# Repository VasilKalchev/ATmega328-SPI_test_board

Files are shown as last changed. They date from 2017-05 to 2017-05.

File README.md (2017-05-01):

# ATmega328-SPI_test_board
ATmega328 test board connected to an SPI device and a few inputs and outputs.

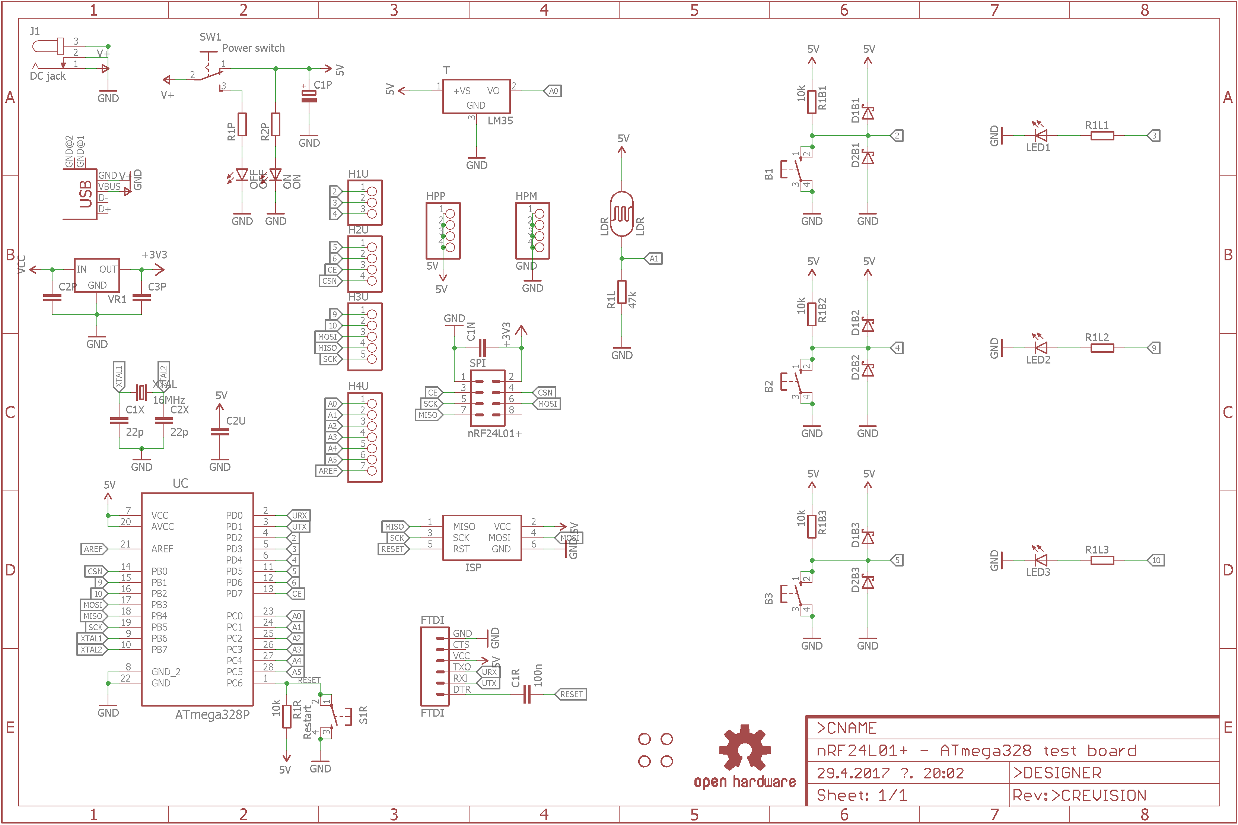
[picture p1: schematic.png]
schematic

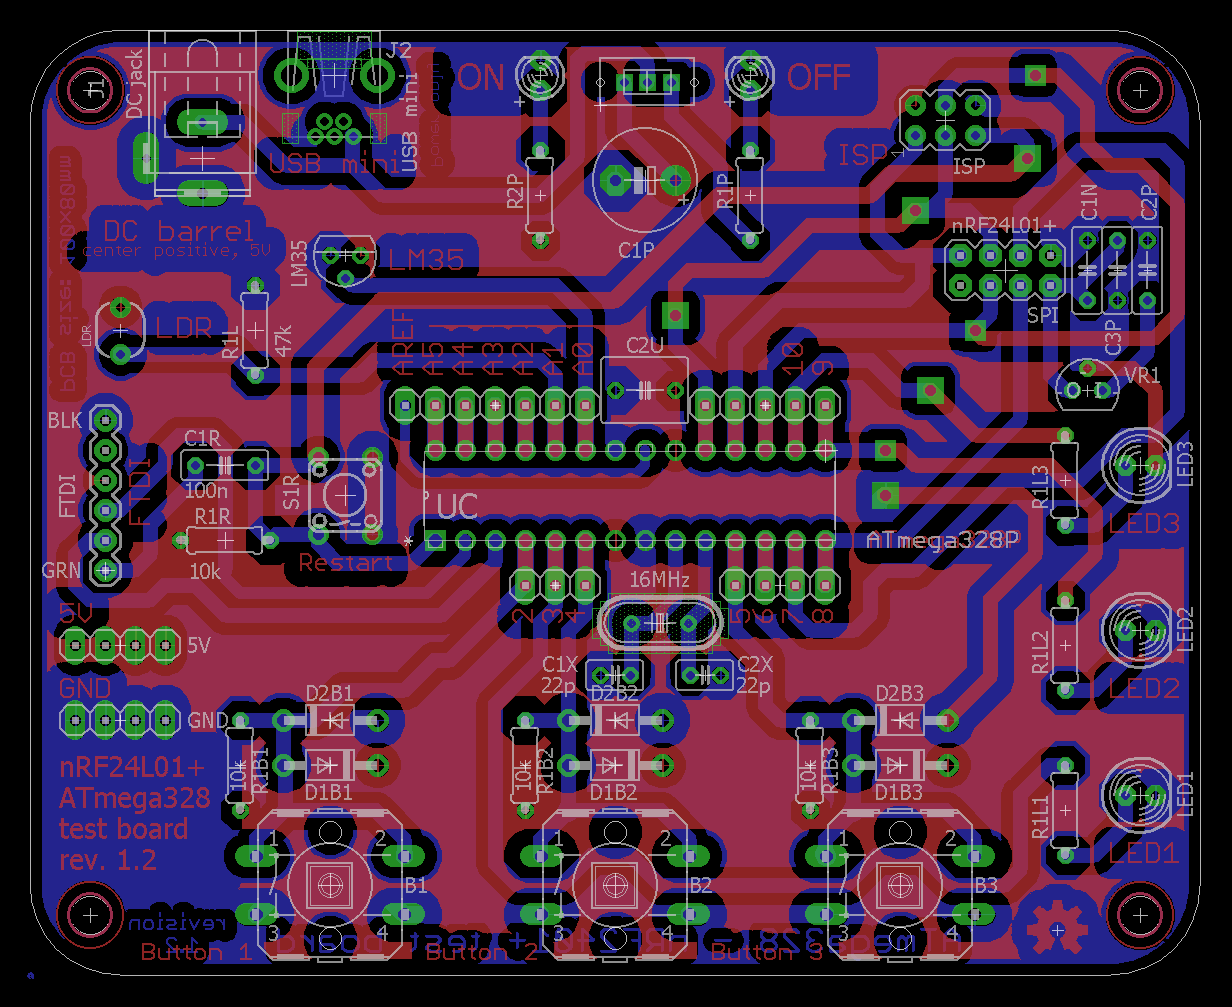
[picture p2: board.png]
board


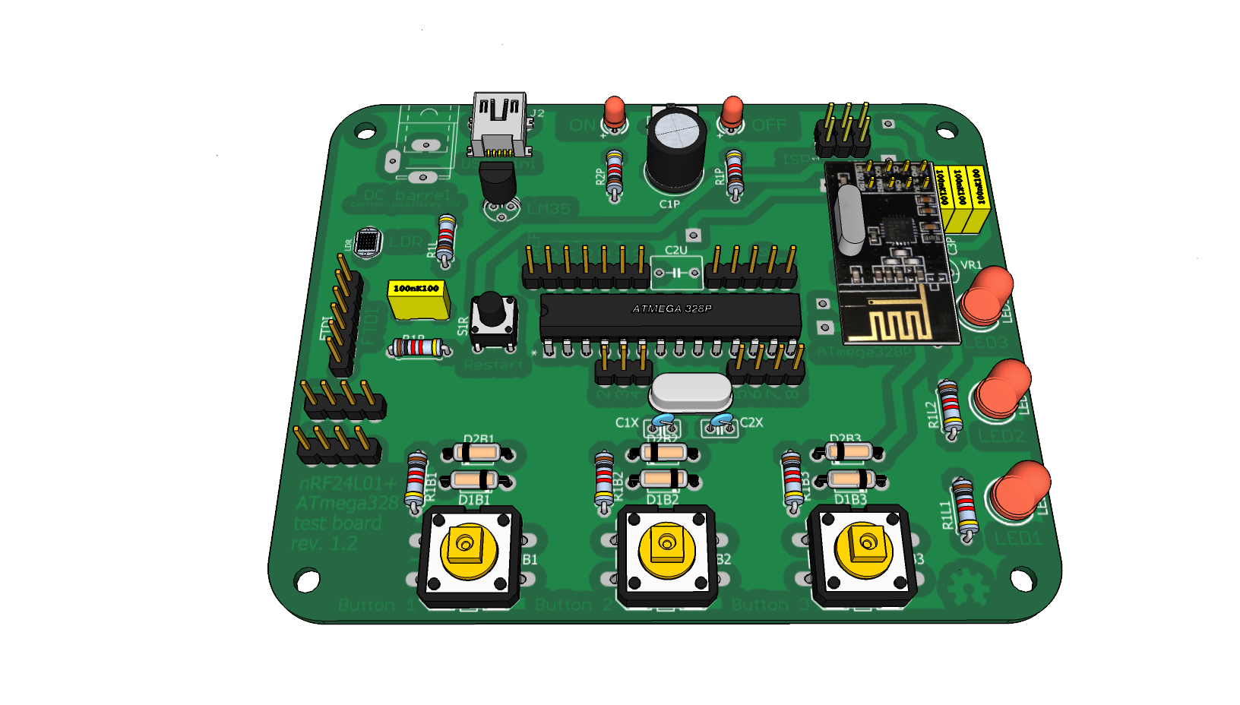
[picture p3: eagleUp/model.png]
model


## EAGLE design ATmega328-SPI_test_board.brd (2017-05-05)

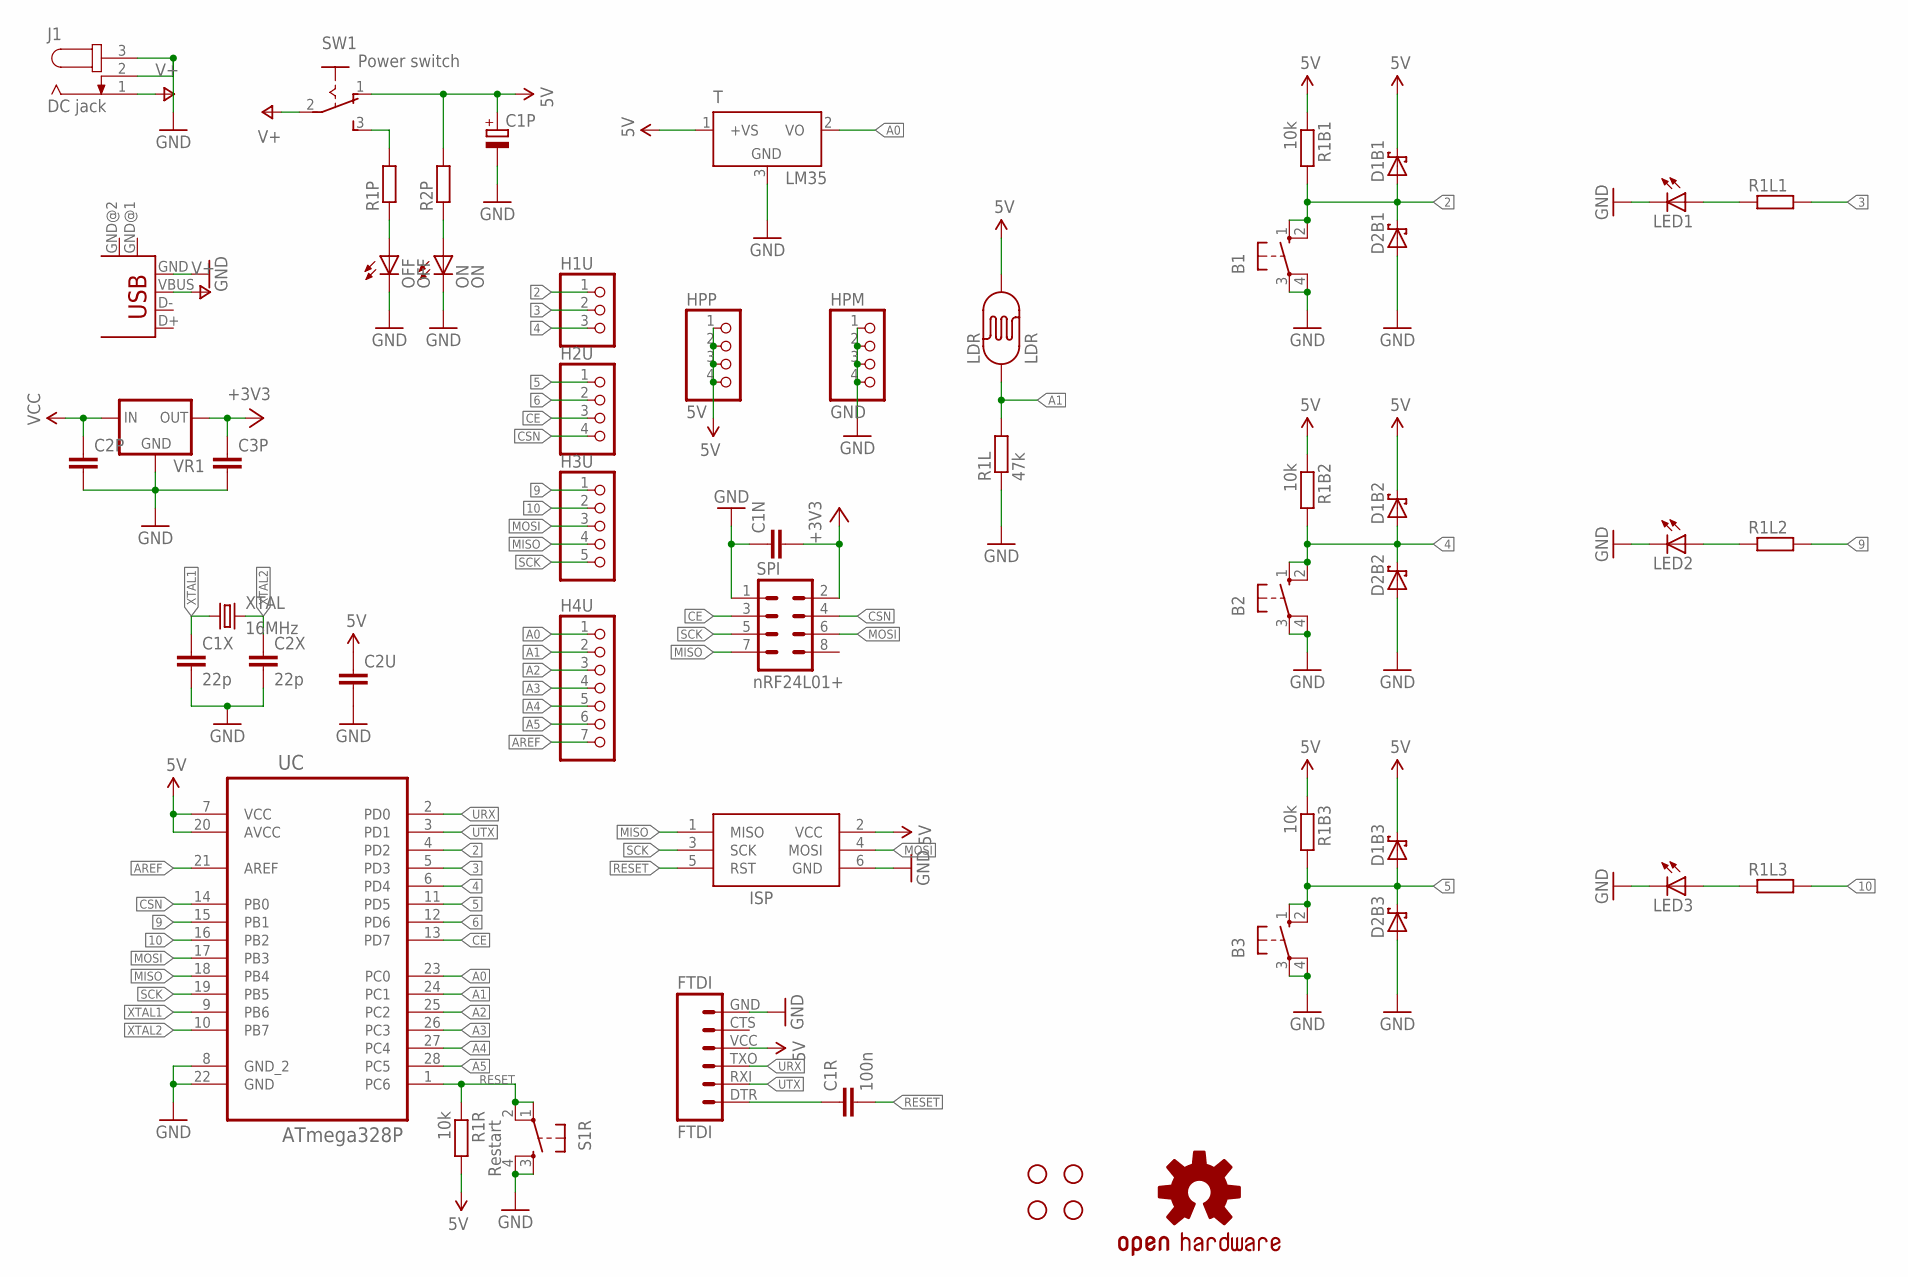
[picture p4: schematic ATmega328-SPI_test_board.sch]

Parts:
B1, B2, B3: 40-XX; B3F-40XX
C1N, C2P, C3P: C-EU050-025X075; C050-025X075
C1P: CPOL-EUE5-8.5; E5-8,5
C1R: 100n; C050-025X075
C1X, C2X: 22p; C025-025X050
C2U: C-EU050-055X075; C050-055X075
D1B1, D1B2, D1B3, D2B1, D2B2, D2B3: SCHOTTKY-DIODEDO41-7; DO41-7
FTDI: FTDI; FTDI_BASIC
H1, H2, H3, H4: STAND-OFF
H1U: PINHD-1X3; 1X03
H2U: PINHD-1X4; 1X04
H3U: PINHD-1X5; 1X05
H4U: PINHD-1X7; 1X07
HPM: GND; 1X04
HPP: 5V; 1X04
ISP: AVRISP-6; AVRISP
J1: DC jack; SPC4078
J2: USB mini; USB-MB-H
LDR: LDR; PHOTOCELL
LED1, LED2, LED3: LED5MM
LOGO1: OSHW-LOGOM-COPPER; OSHW-LOGO-M_COPPER
OFF: OFF; LED3MM
ON: ON; LED3MM
R1B1, R1B2, R1B3, R1R: 10k; 0207/7
R1L: 47k; 0207/7
R1L1, R1L2, R1L3, R1P, R2P: R-EU_0207/7; 0207/7
S1R: Restart; TACTILE-PTH
SPI: nRF24L01+; 2X4; MPN MOD-NRF24LR
SW1: Power switch; SWITCH_2MM
T: LM35; TO92
UC: ATmega328P; DIP254P762X457-28
VR1: 78LXX
XTAL: 16MHz; HC49/S

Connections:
2: B1.1 (S), B1.2 (S1), D1B1.A, D2B1.C, H1U.1, R1B1.2, UC.4 (PD2)
3: H1U.2, R1L1.2, UC.5 (PD3)
4: B2.1 (S), B2.2 (S1), D1B2.A, D2B2.C, H1U.3, R1B2.2, UC.6 (PD4)
5: B3.1 (S), B3.2 (S1), D1B3.A, D2B3.C, H2U.1, R1B3.2, UC.11 (PD5)
5V: C1P.+, C2U.1, D1B1.C, D1B2.C, D1B3.C, FTDI.VCC (4), HPP.1, HPP.2, HPP.3, HPP.4, ISP.2 (VCC), LDR.2, R1B1.1, R1B2.1, R1B3.1, R1R.2, R2P.2, SW1.1, T.1 (+VS), UC.7 (VCC), UC.20 (AVCC)
6: H2U.2, UC.12 (PD6)
9: H3U.1, R1L2.2, UC.15 (PB1)
10: H3U.2, R1L3.2, UC.16 (PB2)
+3V3: C1N.2, C3P.1, SPI.2, VR1.OUT
A0: H4U.1, T.2 (VO), UC.23 (PC0)
A1: H4U.2, LDR.1, R1L.2, UC.24 (PC1)
A2: H4U.3, UC.25 (PC2)
A3: H4U.4, UC.26 (PC3)
A4: H4U.5, UC.27 (PC4)
A5: H4U.6, UC.28 (PC5)
AREF: H4U.7, UC.21 (AREF)
CE: H2U.3, SPI.3, UC.13 (PD7)
CSN: H2U.4, SPI.4, UC.14 (PB0)
GND: B1.3, B1.4 (P1), B2.3, B2.4 (P1), B3.3, B3.4 (P1), C1N.1, C1P.-, C1X.2, C2P.2, C2U.2, C2X.2, C3P.2, D2B1.A, D2B2.A, D2B3.A, FTDI.GND (6), HPM.1, HPM.2, HPM.3, HPM.4, ISP.6 (GND), J1.2, J1.3, J2.GND, LED1.K (C), LED2.K (C), LED3.K (C), OFF.K (C), ON.K (C), R1L.1, S1R.3, S1R.4, SPI.1, T.3 (GND), UC.8 (GND_2), UC.22 (GND), VR1.GND
MISO: H3U.4, ISP.1 (MISO), SPI.7, UC.18 (PB4)
MOSI: H3U.3, ISP.4 (MOSI), SPI.6, UC.17 (PB3)
unnamed: LED1.A, R1L1.1
unnamed: ON.A, R2P.1
unnamed: C1R.1, FTDI.DTR (1)
unnamed: OFF.A, R1P.1
unnamed: R1P.2, SW1.3
unnamed: LED2.A, R1L2.1
unnamed: LED3.A, R1L3.1
RESET: C1R.2, ISP.5 (RST), R1R.1, S1R.1, S1R.2, UC.1 (PC6)
SCK: H3U.5, ISP.3 (SCK), SPI.5, UC.19 (PB5)
URX: FTDI.TXO (3), UC.2 (PD0)
UTX: FTDI.RXI (2), UC.3 (PD1)
V+: J1.1, J2.VBUS, SW1.2
VCC: C2P.1, VR1.IN
XTAL1: C1X.1, UC.9 (PB6), XTAL.1
XTAL2: C2X.1, UC.10 (PB7), XTAL.2

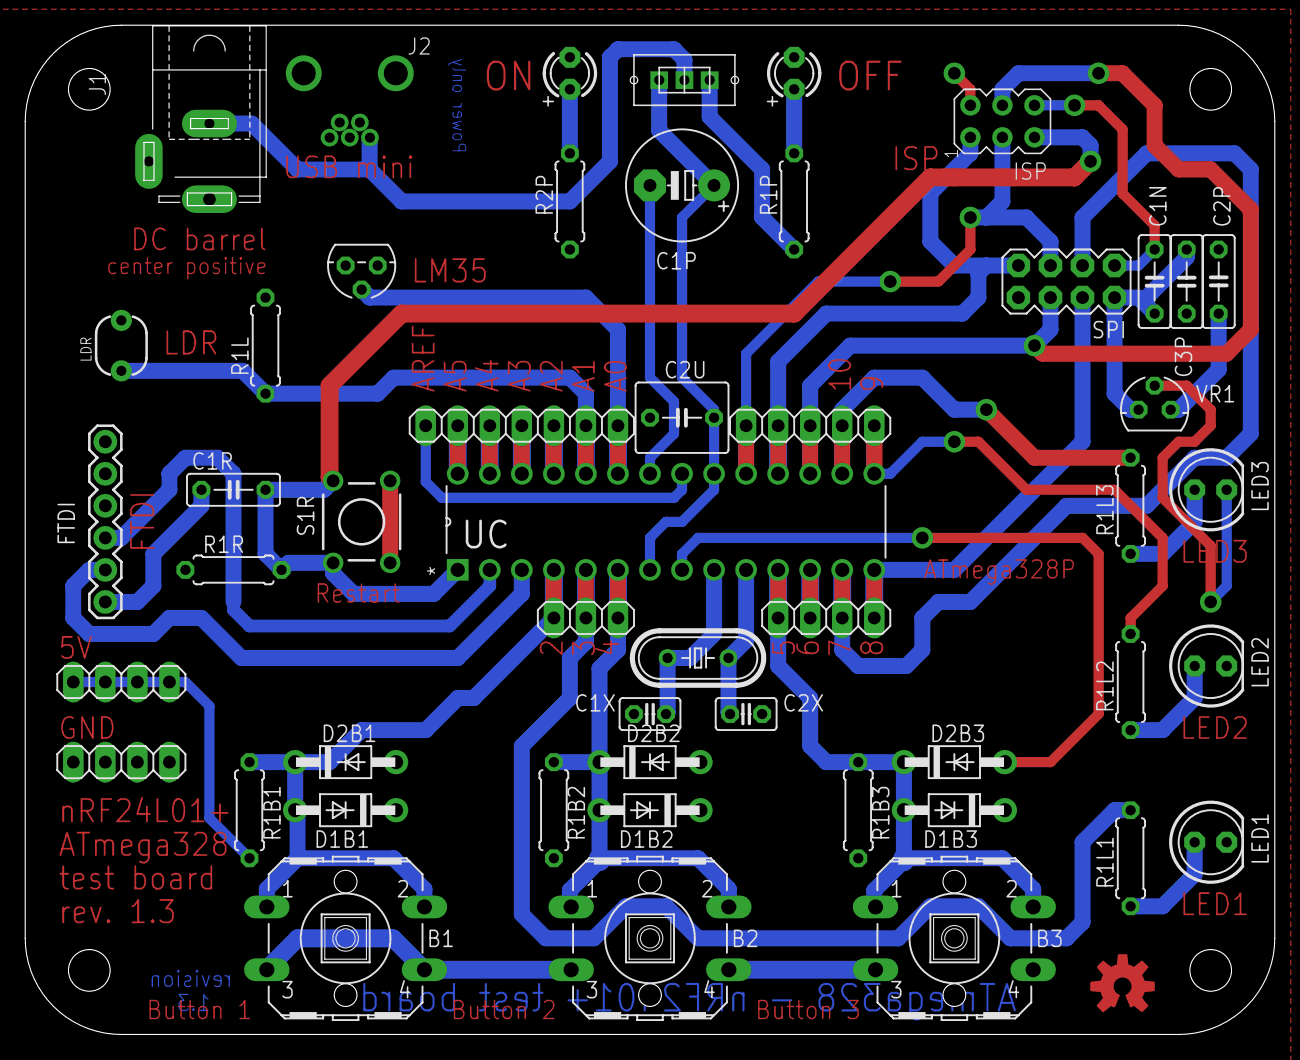
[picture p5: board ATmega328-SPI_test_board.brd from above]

Board: 2 copper layers, 99.1 x 80.0 mm, 55 parts (0 on the bottom side), 36 nets.

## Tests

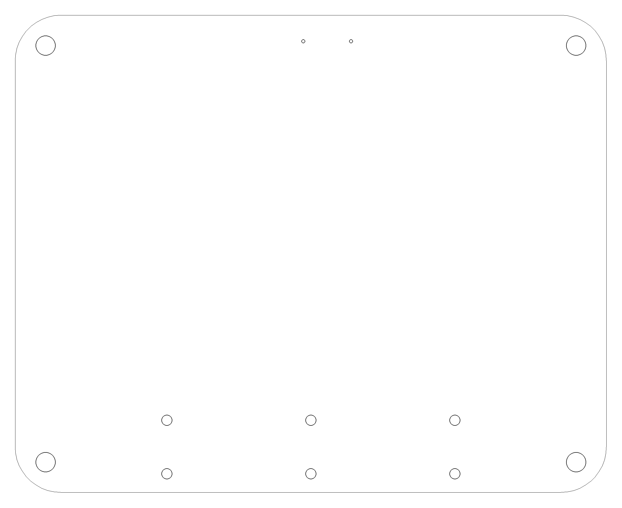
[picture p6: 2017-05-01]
eagleUp/eagleUp_nRF24L01+ - ATmega328 test board_outline.png

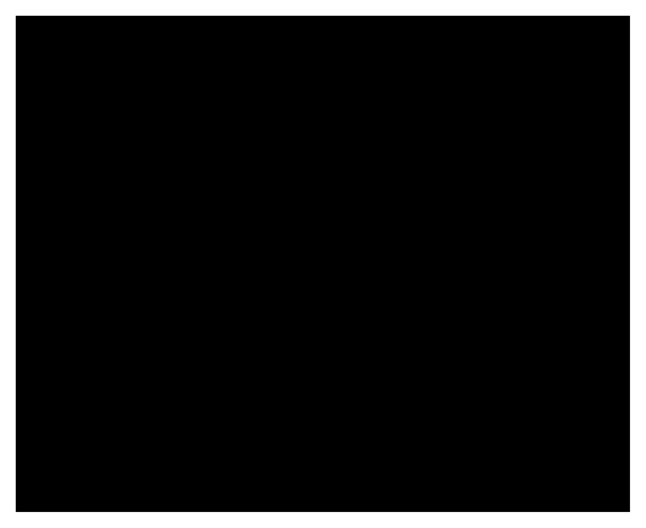
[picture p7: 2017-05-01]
eagleUp/eagleUp_nRF24L01+ - ATmega328 test board_imagesize.png

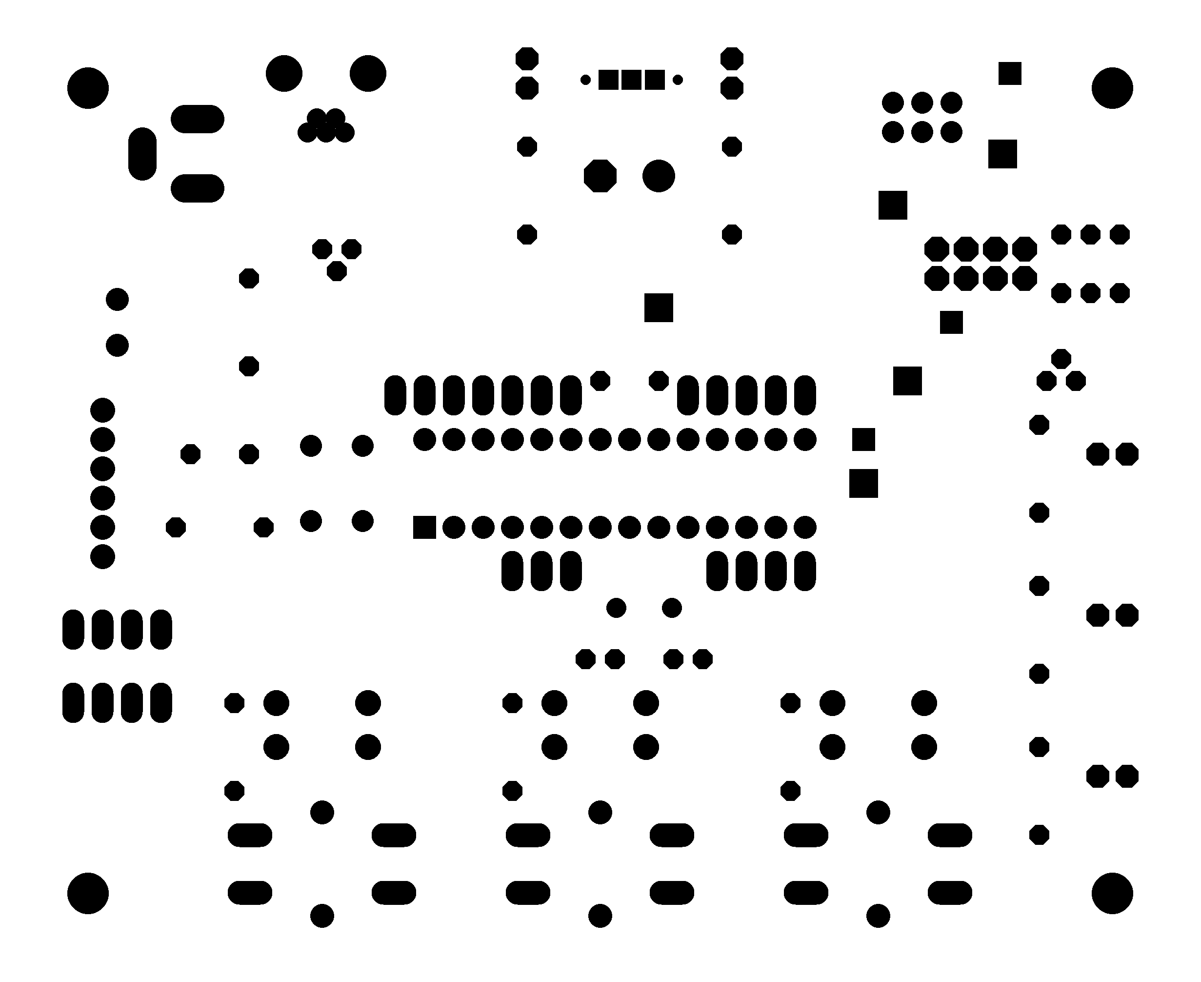
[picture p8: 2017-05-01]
eagleUp/eagleUp_nRF24L01+ - ATmega328 test board_top_mask.png

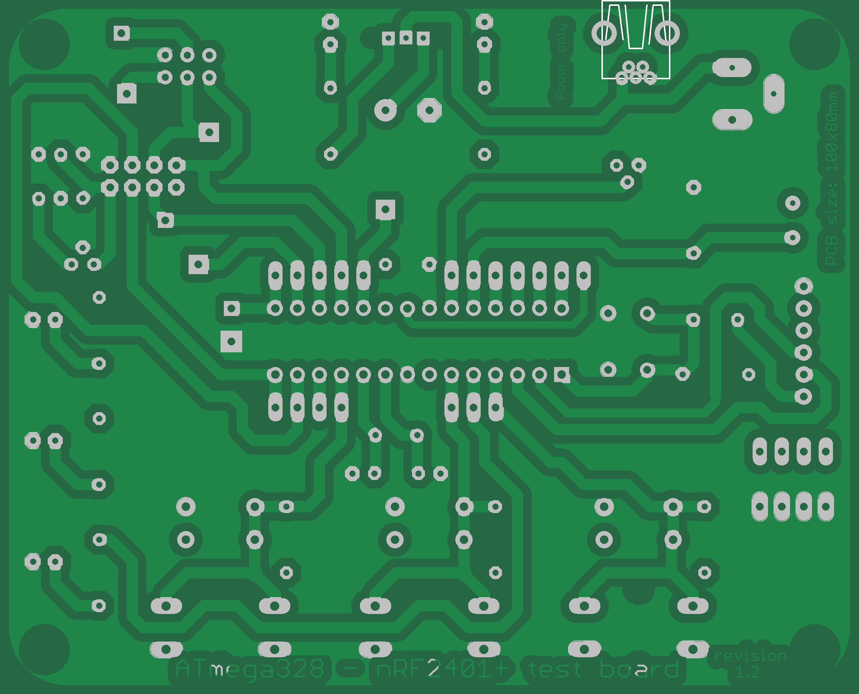
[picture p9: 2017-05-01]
eagleUp/eagleUp_nRF24L01+ - ATmega328 test board_board_bottom.png

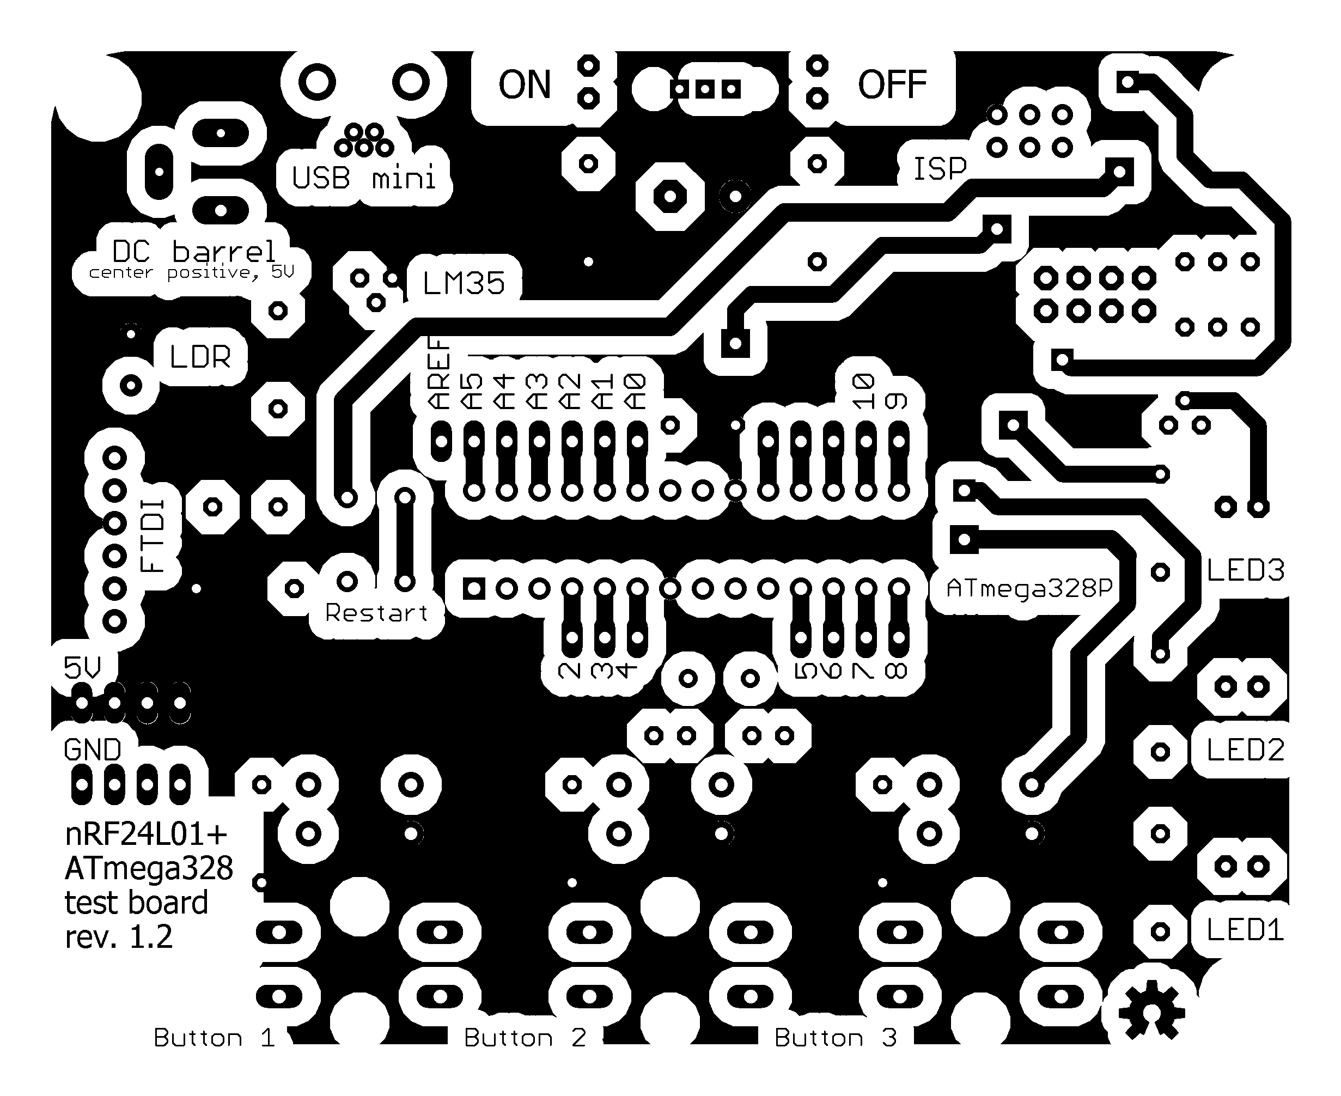
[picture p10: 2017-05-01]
eagleUp/eagleUp_nRF24L01+ - ATmega328 test board_top.png

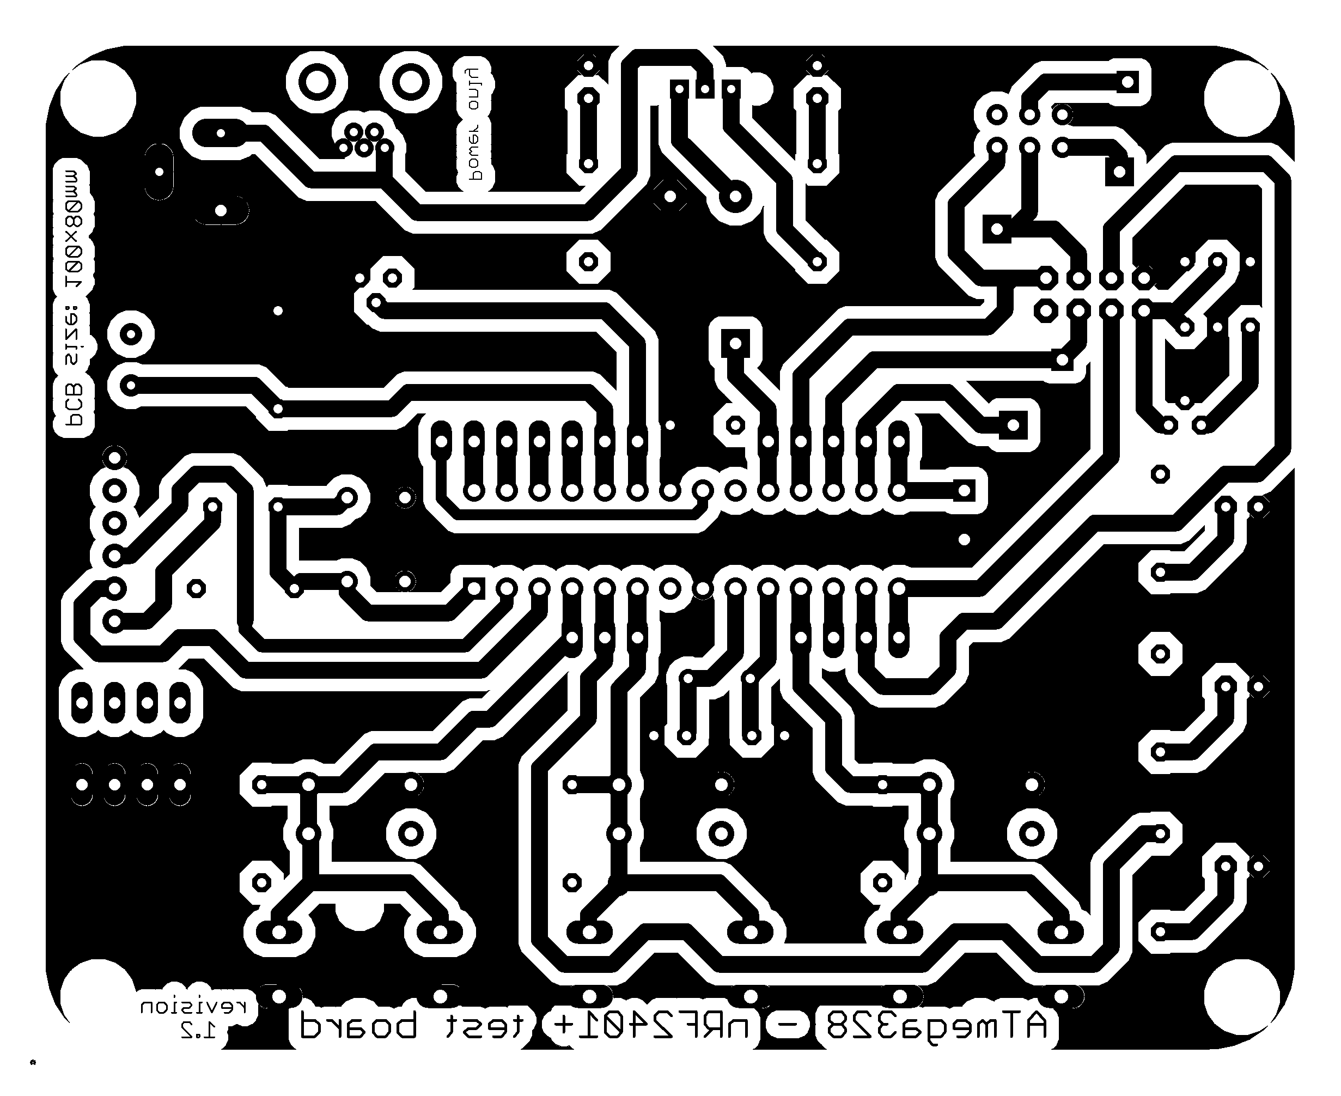
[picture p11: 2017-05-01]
eagleUp/eagleUp_nRF24L01+ - ATmega328 test board_bottom.png

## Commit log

2017-05-01 Added 3.3V regulator
    [nRF24L01+ - ATmega328 test board.brd, nRF24L01+ - ATmega328 test board.sch]
2017-05-01 Exported images
    [ATmega328 - nRF24L01p test board.brd, ATmega328 - nRF24L01p test board.sch, ATmega328-SPI_test_board.brd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]

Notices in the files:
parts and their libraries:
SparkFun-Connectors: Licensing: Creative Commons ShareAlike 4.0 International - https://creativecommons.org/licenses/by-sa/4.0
